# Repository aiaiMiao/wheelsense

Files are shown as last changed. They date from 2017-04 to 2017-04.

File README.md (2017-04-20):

# WheelSense

### Hardware

- 5 [infrared distance sensor](https://www.sparkfun.com/products/242)
- 1 [piezo Buzzer](https://www.adafruit.com/product/160)
- 2 [ultrasonic range finder](https://www.parallax.com/product/28015)
- 2 [coin vibrational motors](http://www.robotshop.com/en/2mm-mini-vibrating-disk-motor.html)
- 1 [Arduino Uno](https://store.arduino.cc/arduino-genuino/arduino-uno-rev3)
- 7 x 3-pin and 2 x 2-pin [screw-terminal headers](https://www.pololu.com/category/177/0.1-2.54-mm-screw-terminal-blocks)
- [Ribbon cable wires](https://www.amazon.com/Ribbon-Cable-10-wire-15ft/dp/B007R9SQQM)

### Tools
- Soldering Iron, Solder
- Wire Strippers
- Zip Ties (for wire management)
- Double-Sided Adhesive Tape
- Electrical Tape
- 3D Printer, Filament, Driver Software

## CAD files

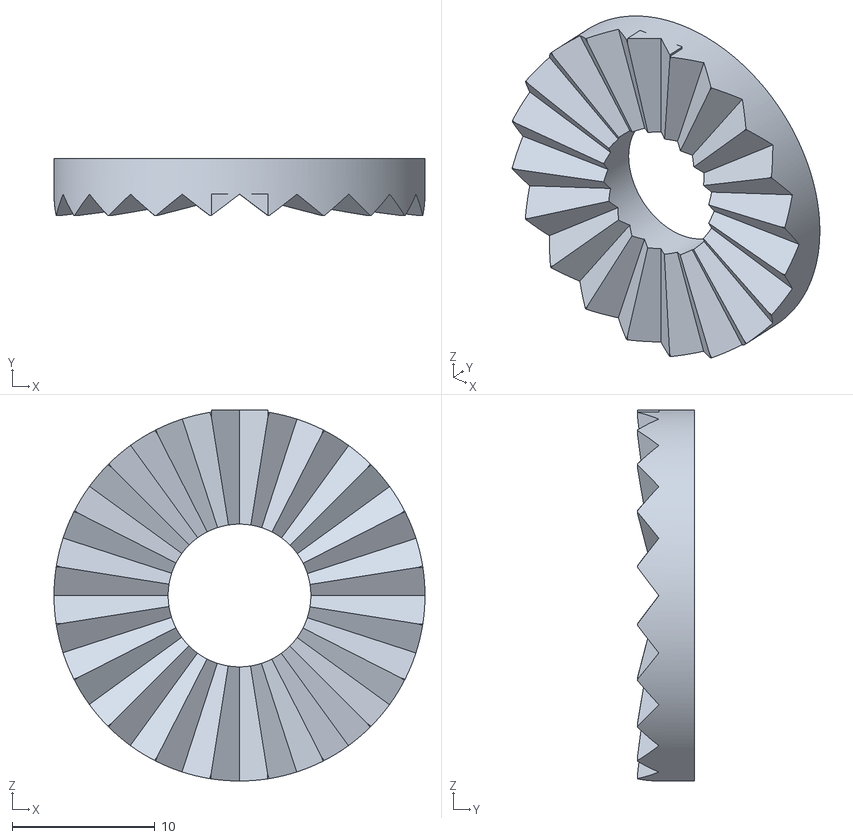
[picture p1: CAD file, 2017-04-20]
designs-4-10-17/Ridge.stl
26.0 x 4.00 x 26.0

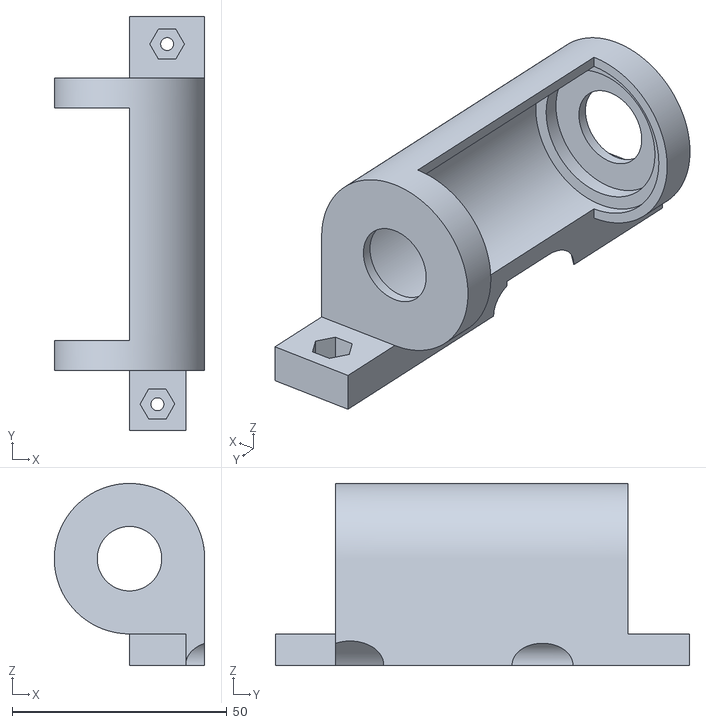
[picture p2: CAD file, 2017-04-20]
designs-4-10-17/RightSide_Mount_NoSpring.stl
35.0 x 96.3 x 42.4

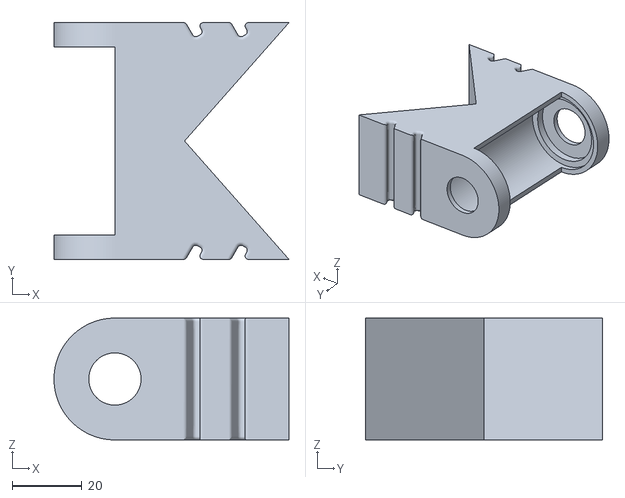
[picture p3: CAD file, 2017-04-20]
designs-4-10-17/ORING.stl
67.5 x 68.0 x 35.0

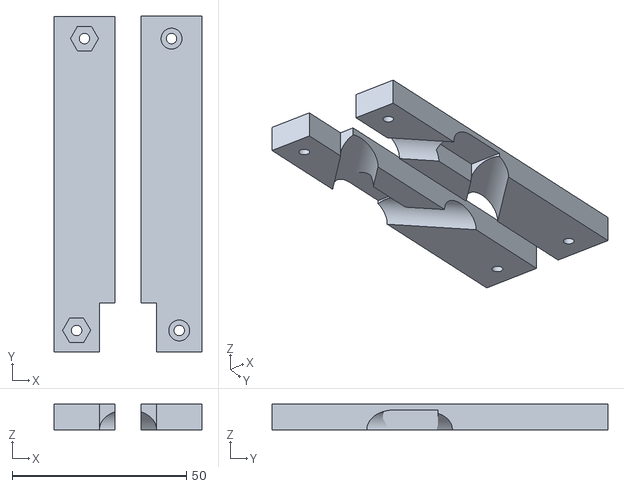
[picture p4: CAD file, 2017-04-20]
designs-4-10-17/mount_clamps.stl
42.5 x 96.3 x 7.36

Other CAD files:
designs-4-10-17/LeftSide_Mount_NoSpring.stl

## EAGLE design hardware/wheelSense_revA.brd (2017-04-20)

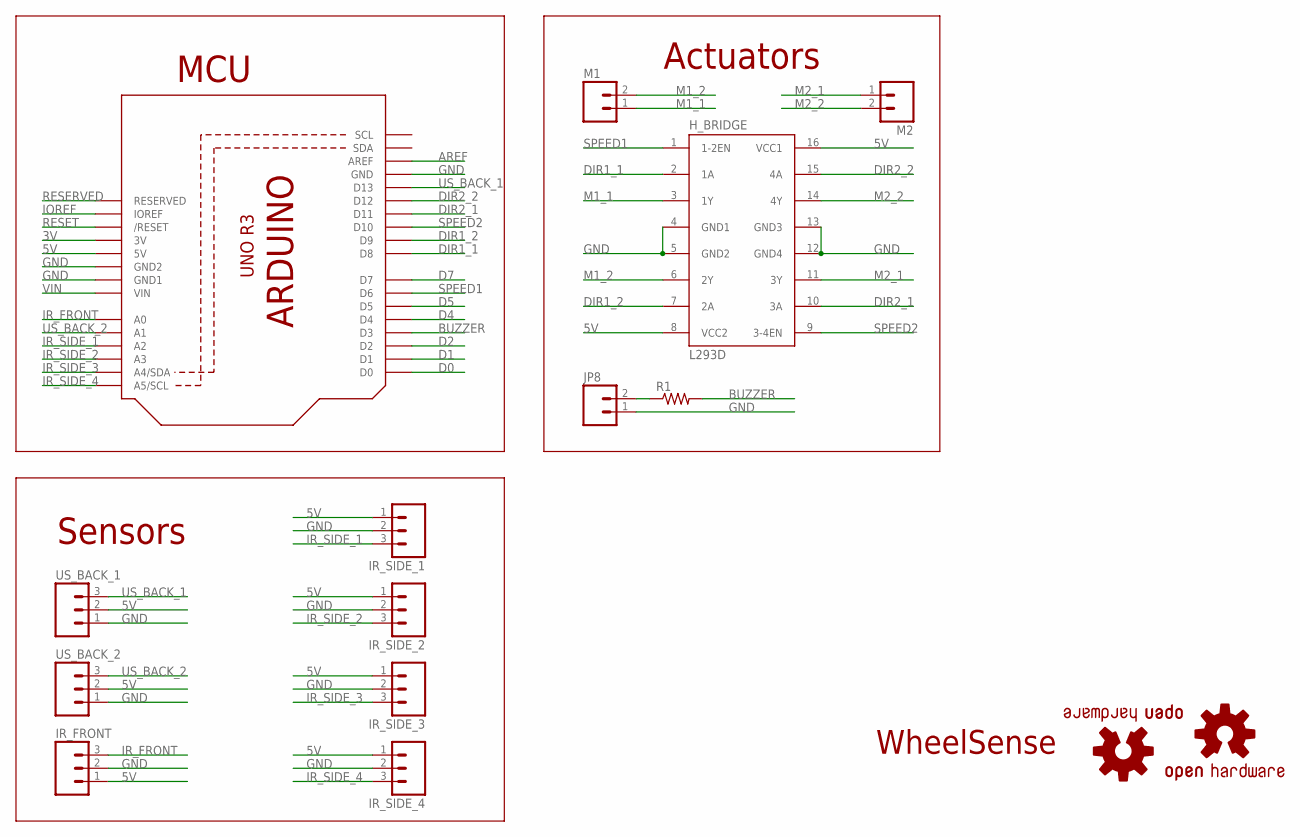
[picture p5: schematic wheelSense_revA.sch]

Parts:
H_BRIDGE: L293D; DIL16
IR_FRONT: M03POLAR; MOLEX-1X3
IR_SIDE_1, IR_SIDE_2, IR_SIDE_3, IR_SIDE_4: M03POLAR; MOLEX-1X3
JP8: M02POLAR; MOLEX-1X2
LOGO1, LOGO2: OSHW-LOGOL-TOP; OSHW_LOGO_L_TOP
M1, M2: M02POLAR; MOLEX-1X2
R1: RESISTORPTH-1/4W; AXIAL-0.4
U$1: ARDUIN0R3_NOHOLES; ARDUINOR3-NOHOLES
US_BACK_1, US_BACK_2: M03POLAR; MOLEX-1X3

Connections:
3V: U$1.3V
5V: H_BRIDGE.8 (VCC2), H_BRIDGE.16 (VCC1), IR_FRONT.1, IR_SIDE_1.1, IR_SIDE_2.1, IR_SIDE_3.1, IR_SIDE_4.1, U$1.5V, US_BACK_1.2, US_BACK_2.2
AREF: U$1.AREF
BUZZER: R1.P$2 (2), U$1.D3
D0: U$1.D0
D1: U$1.D1
D2: U$1.D2
D4: U$1.D4
D5: U$1.D5
D7: U$1.D7
DIR1_1: H_BRIDGE.2 (1A), U$1.D8
DIR1_2: H_BRIDGE.7 (2A), U$1.D9
DIR2_1: H_BRIDGE.10 (3A), U$1.D11
DIR2_2: H_BRIDGE.15 (4A), U$1.D12
GND: H_BRIDGE.4 (GND1), H_BRIDGE.5 (GND2), H_BRIDGE.12 (GND4), H_BRIDGE.13 (GND3), IR_FRONT.2, IR_SIDE_1.2, IR_SIDE_2.2, IR_SIDE_3.2, IR_SIDE_4.2, JP8.1, U$1.GND, U$1.GND1, U$1.GND2, US_BACK_1.1, US_BACK_2.1
IOREF: U$1.IOREF
IR_FRONT: IR_FRONT.3, U$1.A0
IR_SIDE_1: IR_SIDE_1.3, U$1.A2
IR_SIDE_2: IR_SIDE_2.3, U$1.A3
IR_SIDE_3: IR_SIDE_3.3, U$1.A4 (A4/SDA)
IR_SIDE_4: IR_SIDE_4.3, U$1.A5 (A5/SCL)
M1_1: H_BRIDGE.3 (1Y), M1.1
M1_2: H_BRIDGE.6 (2Y), M1.2
M2_1: H_BRIDGE.11 (3Y), M2.1
M2_2: H_BRIDGE.14 (4Y), M2.2
unnamed: JP8.2, R1.P$1 (1)
RESERVED: U$1.RESERVED
RESET: U$1.RESET (/RESET)
SPEED1: H_BRIDGE.1 (1-2EN), U$1.D6
SPEED2: H_BRIDGE.9 (3-4EN), U$1.D10
US_BACK_1: U$1.D13, US_BACK_1.3
US_BACK_2: U$1.A1, US_BACK_2.3
VIN: U$1.VIN

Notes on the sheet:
MCU
Sensors
Actuators
WheelSense

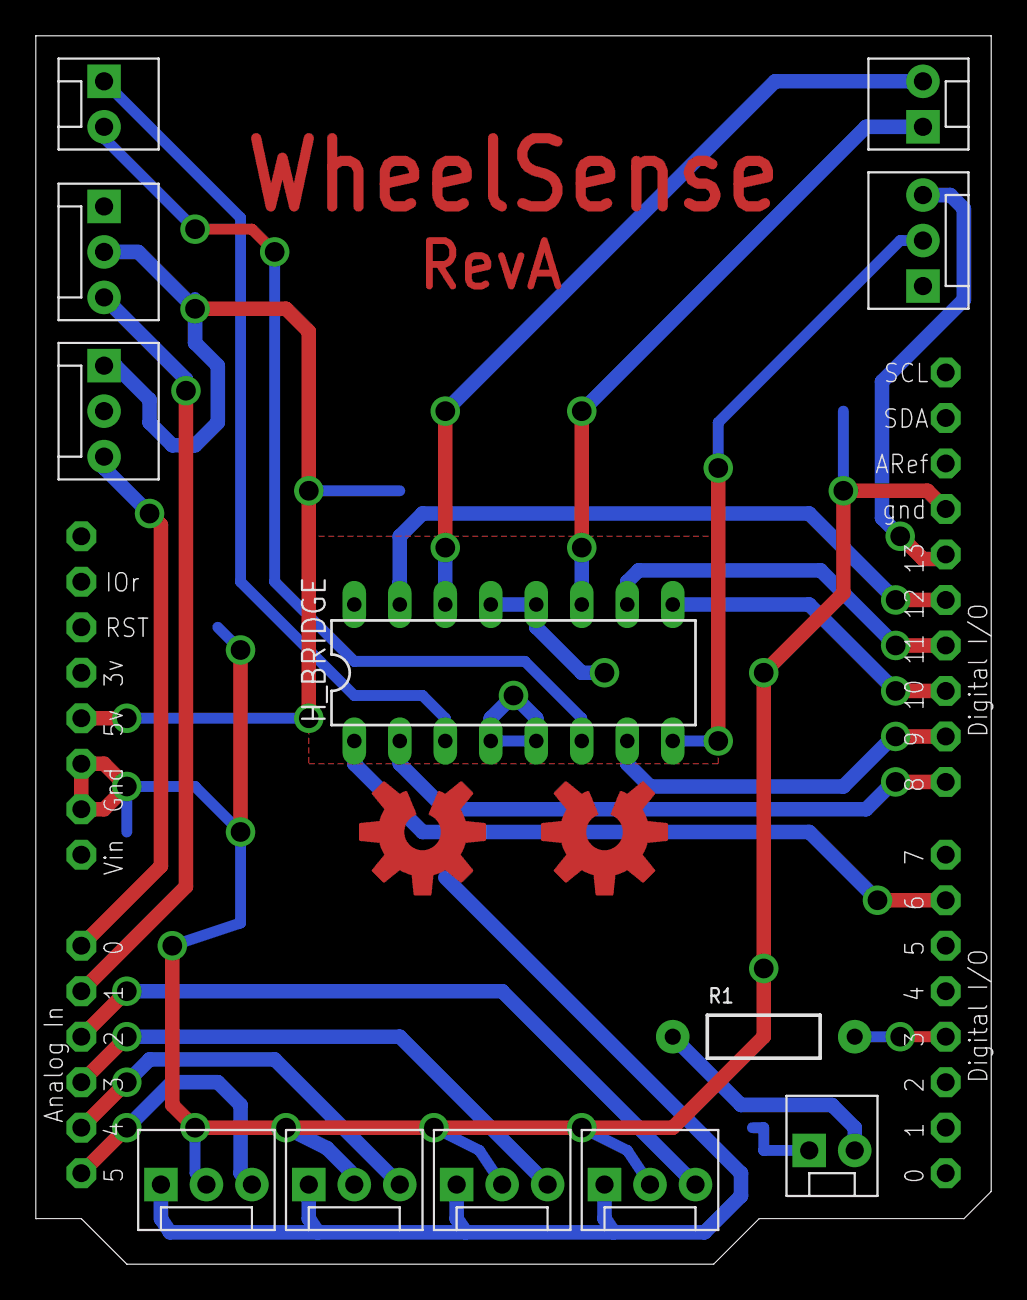
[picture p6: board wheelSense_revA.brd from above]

Board: 2 copper layers, 53.3 x 68.6 mm, 15 parts (0 on the bottom side), 21 nets.

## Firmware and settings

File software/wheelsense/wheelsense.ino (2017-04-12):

#include <Wire.h>

int value;

//#define N_SENSORS 4
//#define THRESHOLD_RAMP 180
//#define THRESHOLD_OBJ 150
//#define THRESHOLD_OBJ_RAMP 350

enum dir {
  FORWARD,
  BACKWARD
};

enum motor {
  M1,
  M2
};

#define N_SENSORS 4
#define THRESHOLD_RAMP 60
#define THRESHOLD_OBJ 150
//#define THRESHOLD_OBJ_RAMP 160
#define THRESHOLD_OBJ_RAMP 170

int sensors[] = {A5, A2, A0, A3};
//int sensors[] = {LB, RB, LT, RT};
int hapticPins[] = {6, 10}; // left, right
int sensorValues[N_SENSORS];
int pinOn[] = {false, false};
int motor1APin = 8;
int motor1BPin = 9;
int motor2APin = 11;
int motor2BPin = 12;
int motor1[2] = {motor1APin, motor1BPin};
int motor2[2] = {motor2APin, motor2BPin};
int* motors[2] = {motor1, motor2};


// FRONT AND BACK
#define NOTE_C5  523
#define NOTE_C7  2093
#define buzzerPin 3
#define botDistPin A1
#define topDistPin 13
#define frontDistPin A4

#define FRONT_DIST_THRESHOLD 115

#define BACK_FEEDBACK_SOUND NOTE_C7
#define FRONT_FEEDBACK_SOUND NOTE_C5

#define VOLTS_PER_UNIT    .0049F        // (.0049 for 10 bit A-D) 
const int sample_size = 5;
int topData[sample_size];
int botData[sample_size];
int idx = 0;
bool sensorReady = false;
int topDistAvg = 0;
int botDistAvg = 0;


void setup() {
    Serial.begin(9600);

    pinMode(hapticPins[0], OUTPUT);
    pinMode(hapticPins[1], OUTPUT);

    pinMode(motor1[0], OUTPUT);
    pinMode(motor1[1], OUTPUT);
    pinMode(motor2[0], OUTPUT);
    pinMode(motor2[1], OUTPUT);
    
    for(int i = 0; i < N_SENSORS; i++) {
      pinMode(sensors[i], INPUT);
    }

    pinMode(buzzerPin, OUTPUT);
    pinMode(botDistPin, INPUT);

    delay(200);
    setDirection(M1, FORWARD); 
    setDirection(M2, FORWARD);
    engageHaptics(false, false); 
}

void engageHaptics(boolean left, boolean right) {

    Serial.print(left);
    Serial.print(right);
    Serial.println("\n");
    if(!left && !right) {
        Serial.println("neither");
        digitalWrite(hapticPins[0], LOW);
        digitalWrite(hapticPins[1], LOW);
        return;
    } else if(left && right) {
        Serial.println("both");
        digitalWrite(hapticPins[0], HIGH);
        digitalWrite(hapticPins[1], HIGH);
        return;
    }

    if(!left) {
        digitalWrite(hapticPins[0], LOW);
    }
    if(!right) {
        digitalWrite(hapticPins[1], LOW);
    }

    if(left) {
        Serial.println("left");
        digitalWrite(hapticPins[0], HIGH);
        delay(200);
        digitalWrite(hapticPins[0], LOW);
    }

    if(right) {
        Serial.println("right");
        digitalWrite(hapticPins[1], HIGH);
        delay(200);
        digitalWrite(hapticPins[1], LOW);
    }


}

int getdistAvg() {
  int topTotal = 0;
  int botTotal = 0;
  for (int i = 0; i < sample_size; i++) {
    topTotal += topData[i];
    botTotal += botData[i];
  }
  int topDistAvg = topTotal / sample_size;
  int botDistAvg = botTotal / sample_size;
  Serial.print("topDistAvg: ");
  Serial.println(topDistAvg);
  Serial.print("botDistAvg: ");
  Serial.println(botDistAvg);
  return min(topDistAvg, botDistAvg);
//  return botDistAvg;
}

void giveFeedback(int distance, int sound) {
  Serial.println("feedback");
  if (distance < 50) {
    if (distance < 15) {
      distance = 15;
    }
    int duration = map(distance, 15, 50, 10, 250);
    tone(buzzerPin, sound, 20);
    delay(duration);
    noTone(buzzerPin);
  }
}

void giveBackFeedback(int distance) {
  giveFeedback(distance, BACK_FEEDBACK_SOUND);
}

void giveFrontFeedback() {
  giveFeedback(25, FRONT_FEEDBACK_SOUND);
}


bool updateDistance() {
  int topProx = pingIt(topDistPin);
  int botProx = pingIt(botDistPin);
//  Serial.print("topProx: ");
//  Serial.println(topProx);
//  Serial.print("botProx: ");
//  Serial.println(botProx);
  
//  float topV = (float)topProx * VOLTS_PER_UNIT;
//  float botV = (float)botProx * VOLTS_PER_UNIT;
//  if (topV < .2 && botV < .2) {
  if (botProx < 3 || topProx < 3) {
    return false;
  }
  
//  int topCm = 60.495 * pow(topV,-1.1904);
//  int botCm = 60.495 * pow(botV,-1.1904);

  topData[idx] = topProx;
  botData[idx++] = botProx;
  if (!sensorReady && idx == 5) {
    sensorReady = true;
  } 
  idx = idx % sample_size;
  return true;
}

void handleBack() {
  int inRange = updateDistance();
  int minDist = getdistAvg();
  Serial.print("minDist: ");
  Serial.println(minDist);
  if (sensorReady && inRange) {
    giveBackFeedback(minDist);
  } else {
    Serial.println("Not in range");
  }
  Serial.println("------------");
}

double frontDist = 300;

boolean handleFront() {
  double dist = analogRead(frontDistPin);
  const double f = 0.3;
  frontDist = f * dist + (1-f) * frontDist;
  
  Serial.print("frontDist:");
  Serial.println(dist);
  if(dist < FRONT_DIST_THRESHOLD) {
    giveFrontFeedback();
    return true;
  } else {
    return false;
  }
}

void setDirection(motor mtr, dir newDir) {
  Serial.println("setDirection");
  int* m = motors[mtr];
  Serial.println(m[0]);
  Serial.println(m[1]);
  if (newDir == FORWARD) {
    Serial.println("Forward");
    digitalWrite(m[0], LOW);
    digitalWrite(m[1], HIGH);
  } else {
    Serial.println("Backward");
    digitalWrite(m[0], HIGH);
    digitalWrite(m[1], LOW);
  }
}

long microsecondsToInches(long microseconds) {
  // According to Parallax's datasheet for the PING))), there are
  // 73.746 microseconds per inch (i.e. sound travels at 1130 feet per
  // second).  This gives the distance travelled by the ping, outbound
  // and return, so we divide by 2 to get the distance of the obstacle.
  // See: http://www.parallax.com/dl/docs/prod/acc/28015-PING-v1.3.pdf
  return microseconds / 74 / 2;
}

long microsecondsToCentimeters(long microseconds) {
  // The speed of sound is 340 m/s or 29 microseconds per centimeter.
  // The ping travels out and back, so to find the distance of the
  // object we take half of the distance travelled.
  return microseconds / 29 / 2;
}

int pingIt(int pingPin) {
    // establish variables for duration of the ping,
  // and the distance result in inches and centimeters:
  long duration, inches, cm;

  // The PING))) is triggered by a HIGH pulse of 2 or more microseconds.
  // Give a short LOW pulse beforehand to ensure a clean HIGH pulse:
  pinMode(pingPin, OUTPUT);
  digitalWrite(pingPin, LOW);
  delayMicroseconds(2);
  digitalWrite(pingPin, HIGH);
  delayMicroseconds(5);
  digitalWrite(pingPin, LOW);

  // The same pin is used to read the signal from the PING))): a HIGH
  // pulse whose duration is the time (in microseconds) from the sending
  // of the ping to the reception of its echo off of an object.
  pinMode(pingPin, INPUT);
  duration = pulseIn(pingPin, HIGH);

  // convert the time into a distance
//  inches = microsecondsToInches(duration);
  cm = microsecondsToCentimeters(duration);
  return cm;
}

void loop() {

  for(int i=0;i<N_SENSORS;i++){
     sensorValues[i] = analogRead(sensors[i])*0.3 + sensorValues[i]*0.7;
  }

    Serial.print(sensorValues[0]);
    Serial.print(", ");
    Serial.print(sensorValues[1]);
    Serial.print(", ");

    Serial.print(sensorValues[2]);
    Serial.print(", ");
    Serial.print(sensorValues[3]);
    Serial.println();
//int sensors[] = {LB, RB, LT, RT};
    boolean leftBottomObs = sensorValues[0] > THRESHOLD_OBJ_RAMP;
    boolean leftBottomRamp = sensorValues[0] < THRESHOLD_RAMP;
    boolean leftBottom = leftBottomObs || leftBottomRamp;
    boolean leftTop =  sensorValues[2] > THRESHOLD_OBJ;
    boolean rightBottomObs = sensorValues[1] > THRESHOLD_OBJ_RAMP;
    boolean rightBottomRamp = sensorValues[1] < THRESHOLD_RAMP;
    boolean rightBottom = rightBottomObs || rightBottomRamp;
    boolean rightTop = sensorValues[3] > THRESHOLD_OBJ;
    boolean left = leftBottom || leftTop;
    boolean right = rightBottom || rightTop;
//    if (leftBottomRamp) {
//      Serial.println("leftBottomRamp");
//    }
//    if (leftBottomObs) {
//      Serial.println("leftBottomObs");
//    }
//    if (leftTop) {
//      Serial.println("leftTop");
//    }
//    if (rightBottomRamp) {
//      Serial.println("rightBottomRamp");
//    }
//    if (rightBottomObs) {
//      Serial.println("rightBottomObs");
//    }
//    if (rightTop) {
//      Serial.println("rightTop");
//    }
    engageHaptics(left, right);

    boolean frontBeep = handleFront();
    if(!frontBeep) {
      handleBack();
    }

    delay(100);
}

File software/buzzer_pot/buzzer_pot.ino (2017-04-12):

#define NOTE_B0  31
#define NOTE_C1  33
#define NOTE_CS1 35
#define NOTE_D1  37
#define NOTE_DS1 39
#define NOTE_E1  41
#define NOTE_F1  44
#define NOTE_FS1 46
#define NOTE_G1  49
#define NOTE_GS1 52
#define NOTE_A1  55
#define NOTE_AS1 58
#define NOTE_B1  62
#define NOTE_C2  65
#define NOTE_CS2 69
#define NOTE_D2  73
#define NOTE_DS2 78
#define NOTE_E2  82
#define NOTE_F2  87
#define NOTE_FS2 93
#define NOTE_G2  98
#define NOTE_GS2 104
#define NOTE_A2  110
#define NOTE_AS2 117
#define NOTE_B2  123
#define NOTE_C3  131
#define NOTE_CS3 139
#define NOTE_D3  147
#define NOTE_DS3 156
#define NOTE_E3  165
#define NOTE_F3  175
#define NOTE_FS3 185
#define NOTE_G3  196
#define NOTE_GS3 208
#define NOTE_A3  220
#define NOTE_AS3 233
#define NOTE_B3  247
#define NOTE_C4  262
#define NOTE_CS4 277
#define NOTE_D4  294
#define NOTE_DS4 311
#define NOTE_E4  330
#define NOTE_F4  349
#define NOTE_FS4 370
#define NOTE_G4  392
#define NOTE_GS4 415
#define NOTE_A4  440
#define NOTE_AS4 466
#define NOTE_B4  494
#define NOTE_C5  523
#define NOTE_CS5 554
#define NOTE_D5  587
#define NOTE_DS5 622
#define NOTE_E5  659
#define NOTE_F5  698
#define NOTE_FS5 740
#define NOTE_G5  784
#define NOTE_GS5 831
#define NOTE_A5  880
#define NOTE_AS5 932
#define NOTE_B5  988
#define NOTE_C6  1047
#define NOTE_CS6 1109
#define NOTE_D6  1175
#define NOTE_DS6 1245
#define NOTE_E6  1319
#define NOTE_F6  1397
#define NOTE_FS6 1480
#define NOTE_G6  1568
#define NOTE_GS6 1661
#define NOTE_A6  1760
#define NOTE_AS6 1865
#define NOTE_B6  1976
#define NOTE_C7  2093
#define NOTE_CS7 2217
#define NOTE_D7  2349
#define NOTE_DS7 2489
#define NOTE_E7  2637
#define NOTE_F7  2794
#define NOTE_FS7 2960
#define NOTE_G7  3136
#define NOTE_GS7 3322
#define NOTE_A7  3520
#define NOTE_AS7 3729
#define NOTE_B7  3951
#define NOTE_C8  4186
#define NOTE_CS8 4435
#define NOTE_D8  4699
#define NOTE_DS8 4978

#define NOTE_C7  2093
#define buzzerPin 3
#define botDistPin A1
//#define topDistPin A3
#define frontDistPin A0

#define FRONT_DIST_THRESHOLD 115

#define BACK_FEEDBACK_SOUND NOTE_C7
#define FRONT_FEEDBACK_SOUND NOTE_C5

#define VOLTS_PER_UNIT    .0049F        // (.0049 for 10 bit A-D) 
const int sample_size = 5;
//int topData[sample_size];
int botData[sample_size];
int idx = 0;
bool sensorReady = false;
//int topDistAvg = 0;
int botDistAvg = 0;

void setup() {
  Serial.begin (9600);
  pinMode(buzzerPin, OUTPUT);
  pinMode(botDistPin, INPUT);
//  pinMode(topDistPin, INPUT);
}

int getdistAvg() {
//  int topTotal = 0;
  int botTotal = 0;
  for (int i = 0; i < sample_size; i++) {
//    topTotal += topData[i];
    botTotal += botData[i];
  }
//  int topDistAvg = topTotal / sample_size;
  int botDistAvg = botTotal / sample_size;
//  Serial.print("topDistAvg: ");
//  Serial.println(topDistAvg);
  Serial.print("botDistAvg: ");
  Serial.println(botDistAvg);
//  return min(topDistAvg, botDistAvg);
  return botDistAvg;
}

void giveFeedback(int distance, int sound) {
  if (distance < 50) {
    if (distance < 15) {
      distance = 15;
    }
    int duration = map(distance, 15, 50, 10, 300);
    tone(buzzerPin, sound, 20);
    delay(duration);
    noTone(buzzerPin);
  }
}

void giveBackFeedback(int distance) {
  giveFeedback(distance, BACK_FEEDBACK_SOUND);
}

void giveFrontFeedback() {
  giveFeedback(25, FRONT_FEEDBACK_SOUND);
}


bool updateDistance() {
//  int topProx = analogRead(topDistPin);
  int botProx = analogRead(botDistPin);
//  Serial.print("topProx: ");
//  Serial.println(topProx);
  Serial.print("botProx: ");
  Serial.println(botProx);
  
//  float topV = (float)topProx * VOLTS_PER_UNIT;
  float botV = (float)botProx * VOLTS_PER_UNIT;
//  if (topV < .2 && botV < .2) {
  if (botV < .2) {
    return false;
  }
  
//  int topCm = 60.495 * pow(topV,-1.1904);
  int botCm = 60.495 * pow(botV,-1.1904);

//  topData[idx] = topCm;
  botData[idx++] = botCm;
  if (!sensorReady && idx == 5) {
    sensorReady = true;
  }
  idx = idx % sample_size;
  return true;
}

void handleBack() {
  int inRange = updateDistance();
  int minDist = getdistAvg();
  Serial.print("minDist: ");
  Serial.println(minDist);
  if (sensorReady && inRange) {
    giveBackFeedback(minDist);
  } else {
    Serial.println("Not in range");
  }
  Serial.println("------------");
}

double frontDist = 300;

boolean handleFront() {
  double dist = analogRead(frontDistPin);
  const double f = 0.3;
  frontDist = f * dist + (1-f) * frontDist;
  
  Serial.print("frontDist:");
  Serial.println(dist);
  if(dist < FRONT_DIST_THRESHOLD) {
    giveFrontFeedback();
    return true;
  } else {
    return false;
  }
}

void loop() {
  boolean frontBeep = handleFront();
  if(!frontBeep) {
    handleBack();
  }
  delay(50);
}

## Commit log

2016-08-18 add sensors code
2016-08-19 buzzer and long-range ultrasonic range finder
    [buzzer_pot.ino]
2016-08-20 update buzzer pot for arduino
    [buzzer_pot.ino]
2016-08-21 handle front and back in buzzer
    [buzzer_pot.ino]
2016-08-21 all sensors included(4)
2016-08-21 update thresholds and sensor pins
2016-08-21 update ramp sensors
2016-08-21 small fixes from testing
    [buzzer_pot.ino]
2017-04-20 readme and more cleaning
    [wheelSense_revA.brd, wheelSense_revA.sch]
2017-04-20 added 3d model files, both STL and gcode
    [LeftSide_Mount_NoSpring.stl, ORING.stl, Ridge.stl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]

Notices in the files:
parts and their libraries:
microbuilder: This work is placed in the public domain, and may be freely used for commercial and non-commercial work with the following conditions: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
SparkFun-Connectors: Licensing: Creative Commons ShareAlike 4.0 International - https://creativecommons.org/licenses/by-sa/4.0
